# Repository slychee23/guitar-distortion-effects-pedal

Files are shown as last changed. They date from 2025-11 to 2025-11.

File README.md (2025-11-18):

# guitar-distortion-effects-pedal
This is JUJUBE--a custom analog guitar distortion effects pedal using the RC4558 dual op-amp.
<br>
Includes CAD of enclosure with labeled knob controls, optimizing component layouts
<br>
The circuit features:  
<br>
-Three potentiometers for user-adjustable gain, tone, and volume control  
<br>
-A 3PDT footswitch for true bypass switching, with integrated LED indicators for visual feedback  
<br>
-Two 1N4148 silicon diodes configured for symmetrical clipping, creating a distinct, aggressive distortion tone  
<br>

<p align="center">
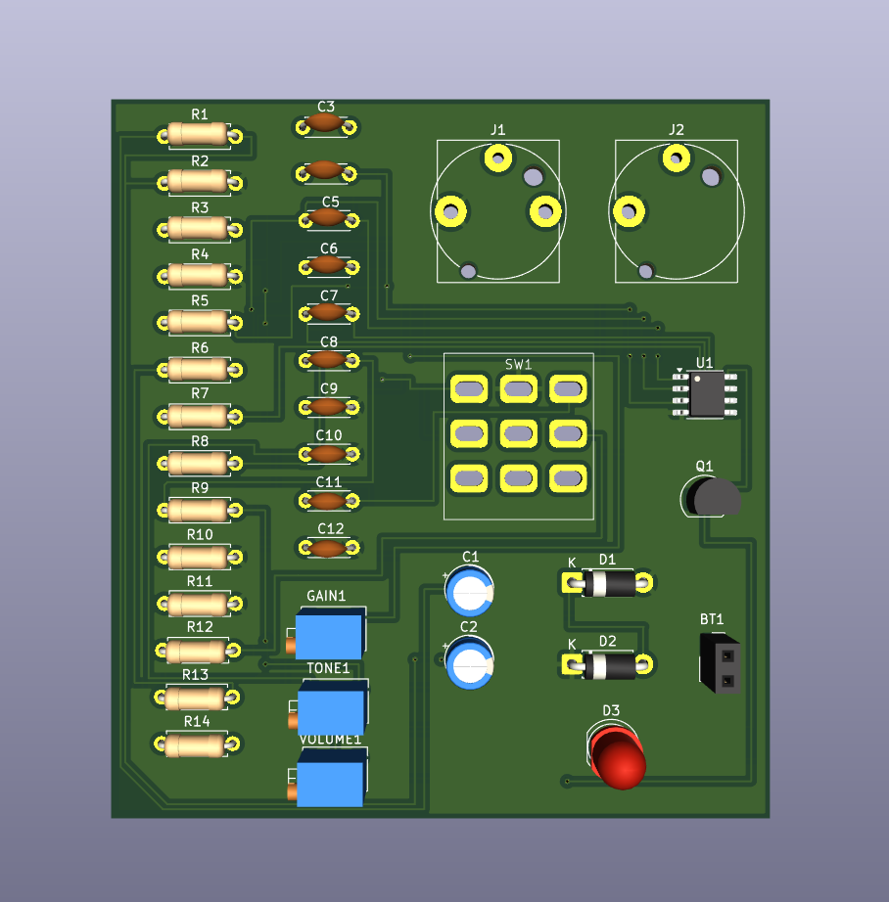
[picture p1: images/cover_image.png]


## Schematic
<p align="center">
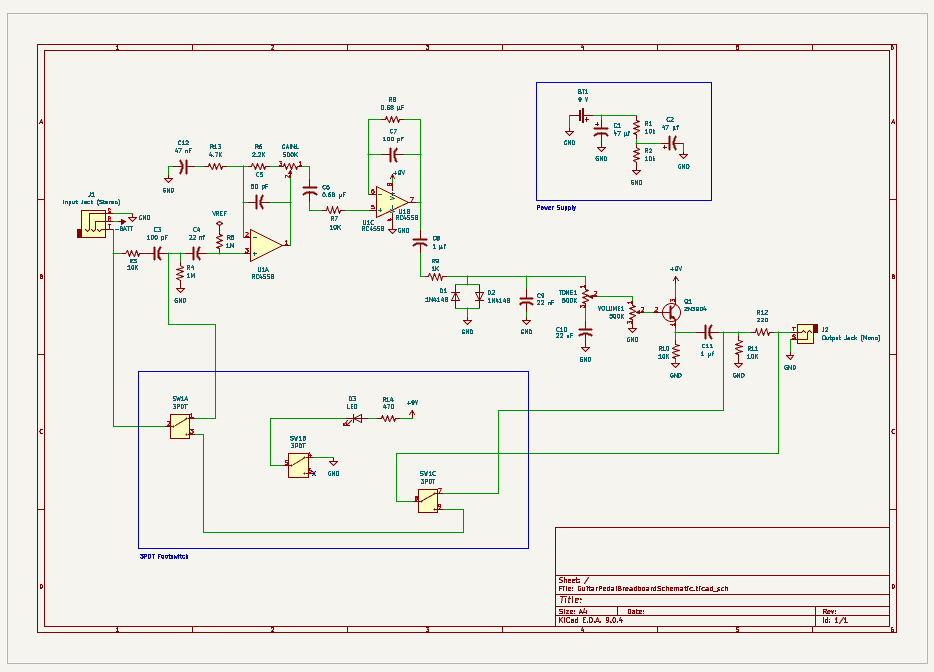
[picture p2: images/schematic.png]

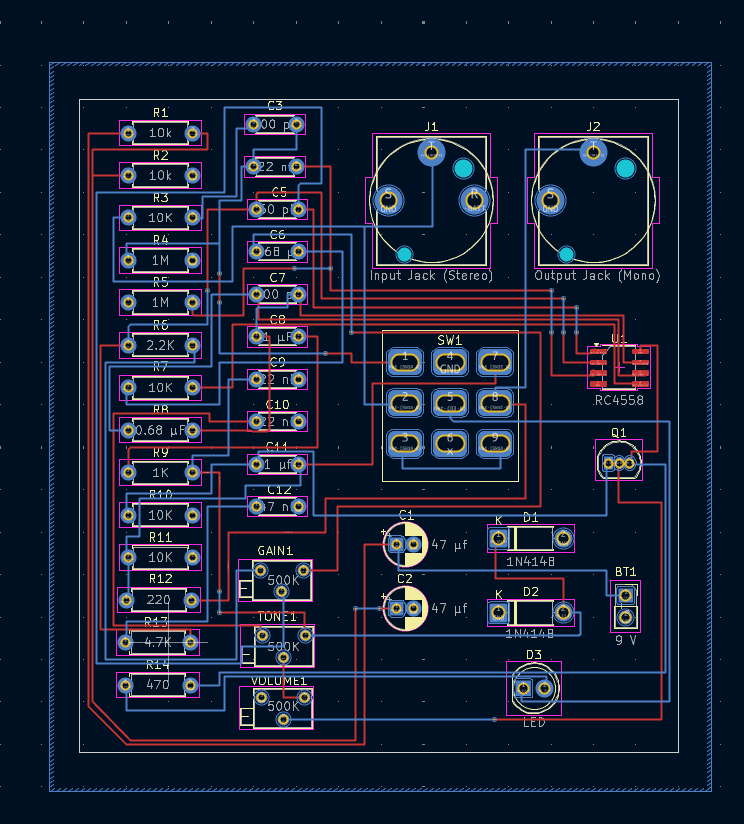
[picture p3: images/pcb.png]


## Enclosure
<p align="center">
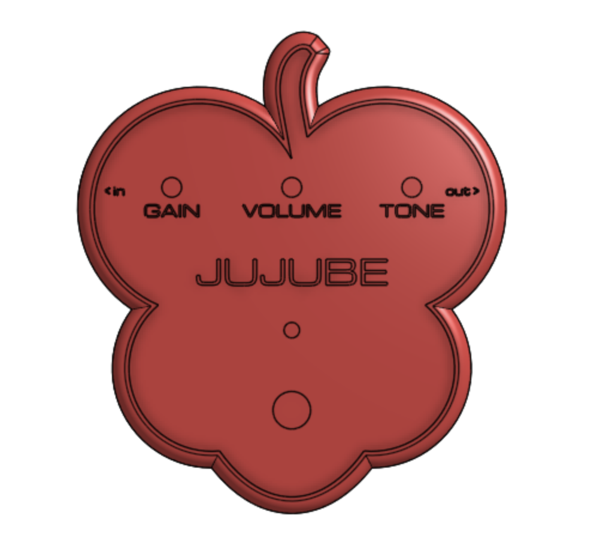
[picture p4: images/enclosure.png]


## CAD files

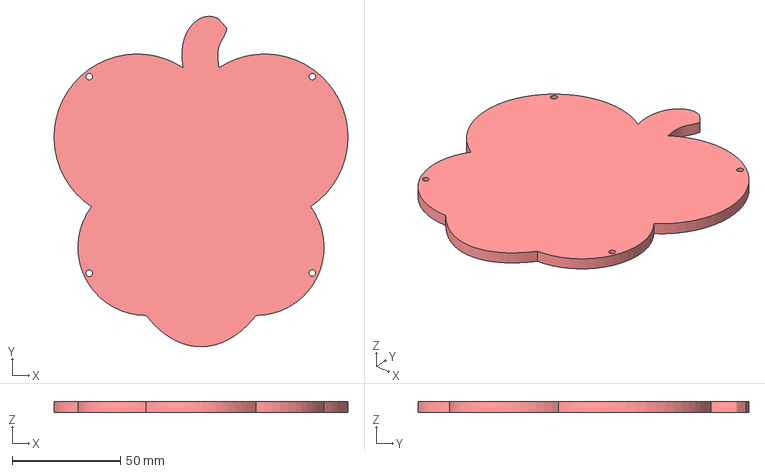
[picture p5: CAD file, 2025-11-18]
enclosure-cad/enclosure-lid.step
135.7 x 152.5 x 5.08 mm

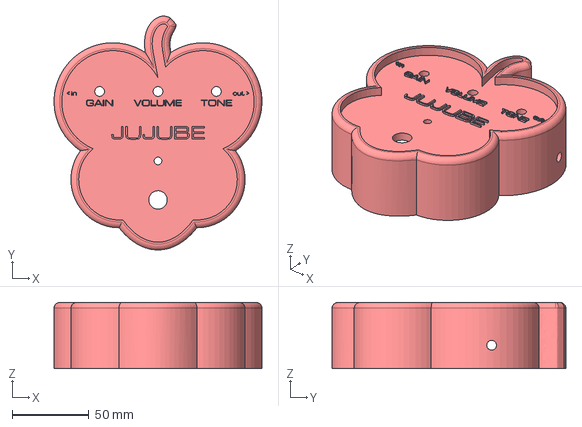
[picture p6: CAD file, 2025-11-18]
enclosure-cad/enclosure-body.step
135.7 x 152.5 x 43.2 mm

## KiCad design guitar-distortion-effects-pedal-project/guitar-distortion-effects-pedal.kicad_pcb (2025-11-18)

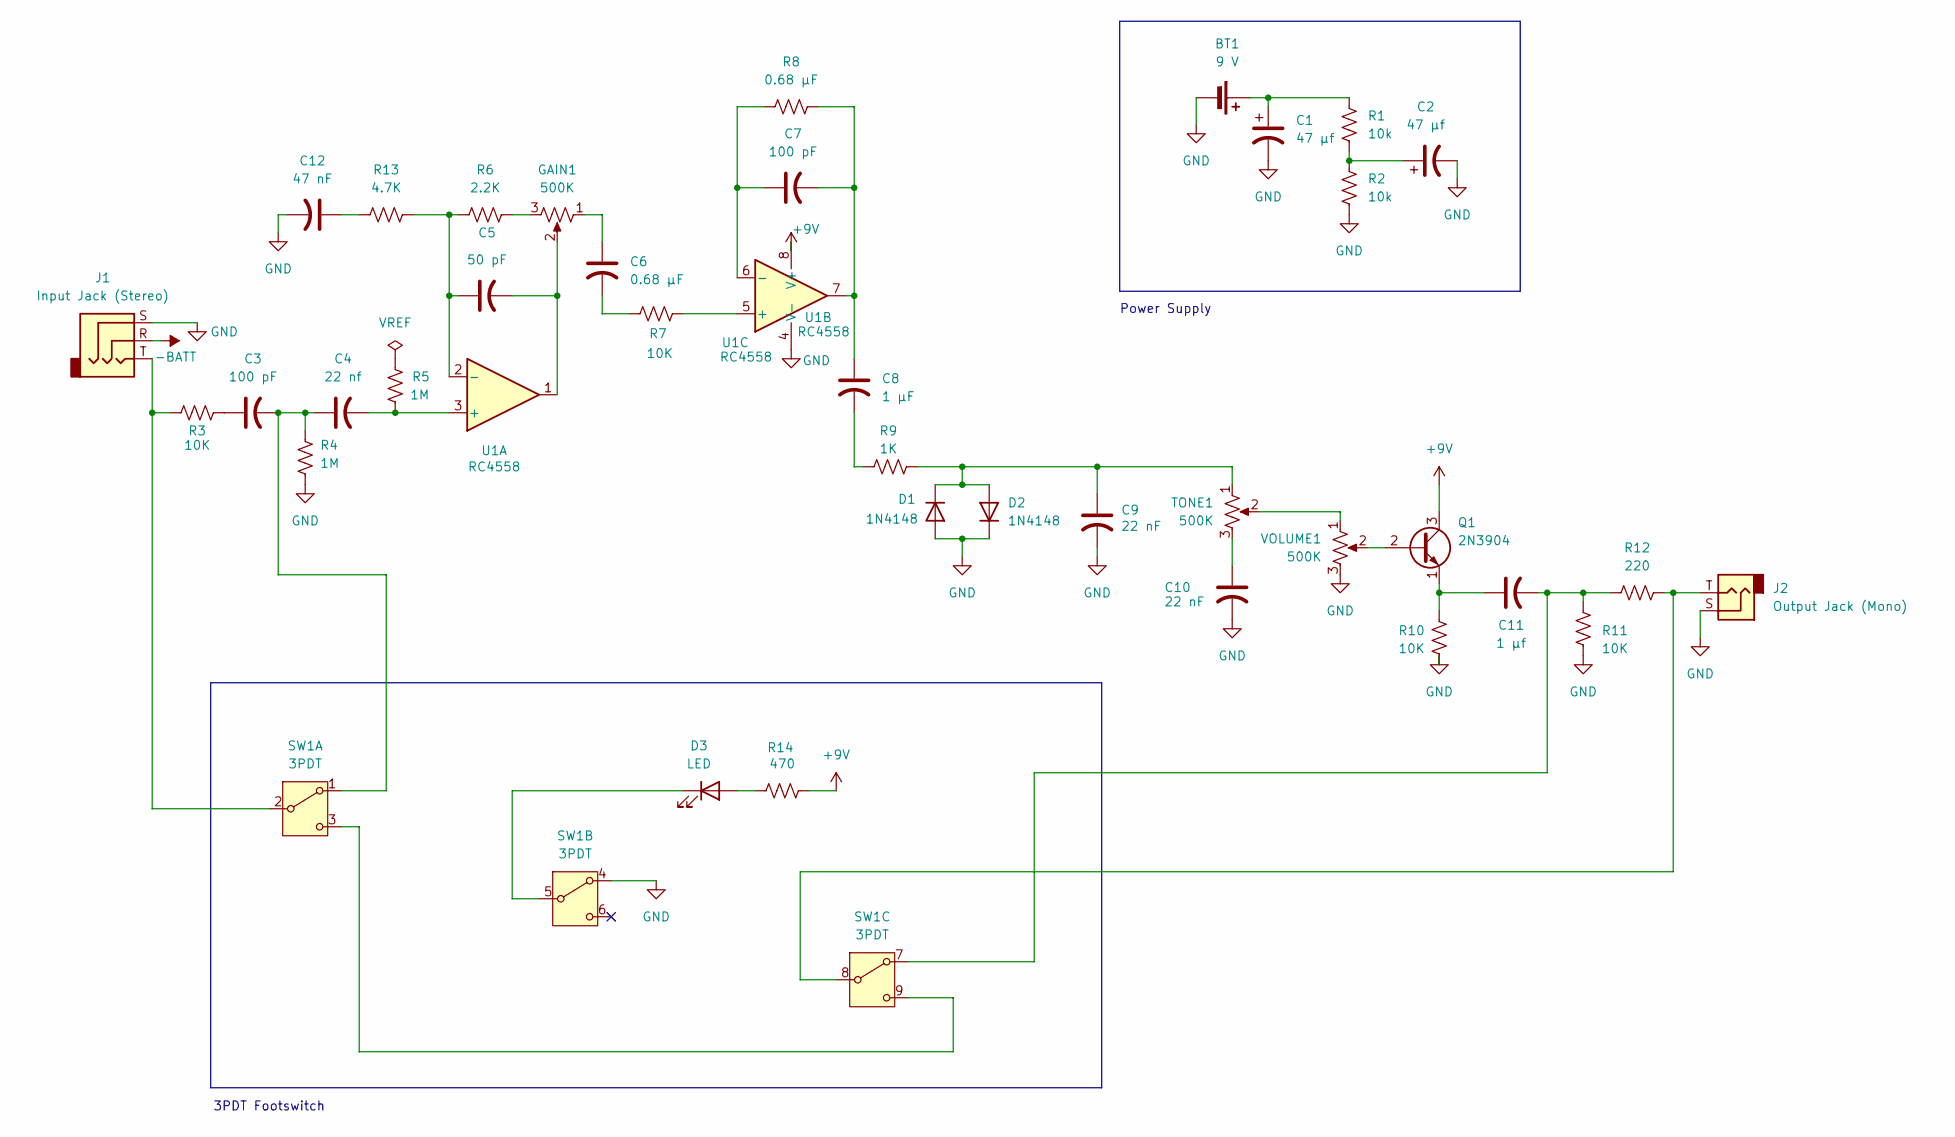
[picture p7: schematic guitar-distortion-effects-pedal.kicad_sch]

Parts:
BT1: 9 V; PinSocket_1x02_P2.54mm_Vertical
C1, C2: 47 μf; CP_Radial_D5.0mm_P2.00mm
C3, C7: 100 pF; C_Disc_D4.3mm_W1.9mm_P5.00mm
C4: 22 nf; C_Disc_D4.3mm_W1.9mm_P5.00mm
C5: 50 pF; C_Disc_D4.3mm_W1.9mm_P5.00mm
C6: 0.68 μF; C_Disc_D4.3mm_W1.9mm_P5.00mm
C8: 1 μF; C_Disc_D4.3mm_W1.9mm_P5.00mm
C9, C10: 22 nF; C_Disc_D4.3mm_W1.9mm_P5.00mm
C11: 1 μf; C_Disc_D4.3mm_W1.9mm_P5.00mm
C12: 47 nF; C_Disc_D4.3mm_W1.9mm_P5.00mm
D1, D2: 1N4148; D_DO-41_SOD81_P7.62mm_Horizontal
D3: LED; LED_D5.0mm
GAIN1: 500K; Potentiometer_Bourns_3266X_Horizontal
J1: Input Jack (Stereo); Jack_6.35mm_Neutrik_NJ3FD-V_Vertical
J2: Output Jack (Mono); Jack_6.35mm_Neutrik_NJ2FD-V_Vertical
Q1: 2N3904; TO-92_Inline
R1, R2: 10k; R_Axial_DIN0207_L6.3mm_D2.5mm_P7.62mm_Horizontal
R3, R7, R10, R11: 10K; R_Axial_DIN0207_L6.3mm_D2.5mm_P7.62mm_Horizontal
R4, R5: 1M; R_Axial_DIN0207_L6.3mm_D2.5mm_P7.62mm_Horizontal
R6: 2.2K; R_Axial_DIN0207_L6.3mm_D2.5mm_P7.62mm_Horizontal
R8: 0.68 μF; R_Axial_DIN0207_L6.3mm_D2.5mm_P7.62mm_Horizontal
R9: 1K; R_Axial_DIN0207_L6.3mm_D2.5mm_P7.62mm_Horizontal
R12: 220; R_Axial_DIN0207_L6.3mm_D2.5mm_P7.62mm_Horizontal
R13: 4.7K; R_Axial_DIN0207_L6.3mm_D2.5mm_P7.62mm_Horizontal
R14: 470; R_Axial_DIN0207_L6.3mm_D2.5mm_P7.62mm_Horizontal
SW1: 3PDT; 3PDT_Footswitch
TONE1: 500K; Potentiometer_Bourns_3266X_Horizontal
U1: RC4558; SOIC-8_3.9x4.9mm_P1.27mm
VOLUME1: 500K; Potentiometer_Bourns_3266X_Horizontal

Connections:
+9V: Q1.3 (C), R14.2, U1.8 (V+)
-BATT: J1.R
GND: BT1.2 (-), C1.2, C2.2, C9.2, C10.2, C12.2, D1.2 (A), D2.1 (K), J1.S, J2.S, R2.2, R4.2, R10.2, R11.2, SW1.4 (A), U1.4 (V-), VOLUME1.3
unnamed: BT1.1 (+), C1.1, R1.1
unnamed: C2.1, R1.2, R2.1
unnamed: C3.1, R3.2
unnamed: C5.2, GAIN1.2, U1.1
unnamed: C6.1, GAIN1.1
unnamed: C6.2, R7.1
unnamed: C7.2, C8.1, R8.2, U1.7
unnamed: C8.2, R9.1
unnamed: C10.1, TONE1.3
unnamed: C12.1, R13.1
unnamed: C9.1, D1.1 (K), D2.2 (A), R9.2, TONE1.1
unnamed: D3.2 (A), R14.1
unnamed: D3.1 (K), SW1.5 (B)
unnamed: GAIN1.3, R6.2
unnamed: Q1.2 (B), VOLUME1.2
unnamed: C11.1, Q1.1 (E), R10.1
unnamed: C3.2, C4.1, R4.1, SW1.1 (A)
unnamed: J1.T, R3.1, SW1.2 (B)
unnamed: SW1.3 (C), SW1.9 (C)
unnamed: C11.2, R11.1, R12.1, SW1.7 (A)
unnamed: J2.T, R12.2, SW1.8 (B)
unnamed: TONE1.2, VOLUME1.1
unnamed: C4.2, R5.2, U1.3 (+)
unnamed: C5.1, R6.1, R13.2, U1.2 (-)
unnamed: R7.2, U1.5 (+)
unnamed: C7.1, R8.1, U1.6 (-)

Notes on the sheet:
Power Supply
3PDT Footswitch

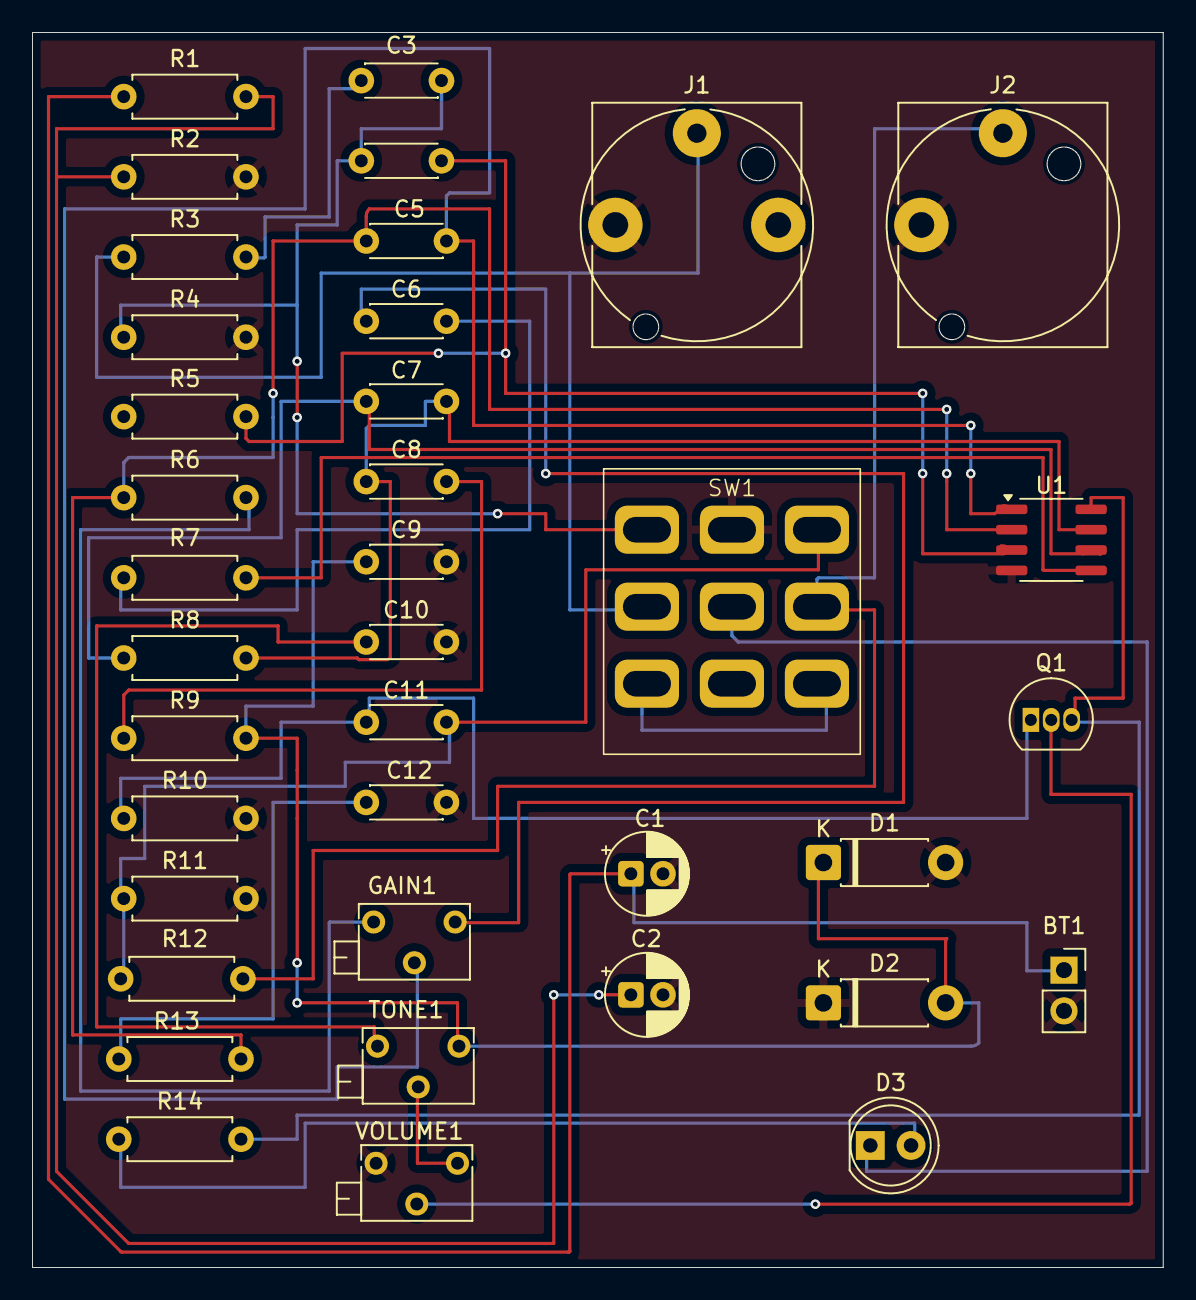
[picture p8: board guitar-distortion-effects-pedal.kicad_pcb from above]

Board: 2 copper layers, 70.5 x 77.0 mm, 38 parts (0 on the bottom side), 28 nets.
